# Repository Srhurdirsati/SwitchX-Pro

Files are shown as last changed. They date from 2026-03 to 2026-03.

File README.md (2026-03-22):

# SwitchX-Pro

SwitchX Pro is a 6-channel WiFi smart switch system with real-time clock automation, allowing precise control of home appliances anytime, anywhere.

## Working

1 - *Put the ESP32 in boot mode and connect it to your PCB*

2 - *Use arduino IDE to upload the CODE to the Board and* **make sure that you have entered correct SSID and it's password in the code** . *The following libraries should downloaded and transferred in the microcontroller :*

`<WiFi.h>`

`<WebServer.h>`

`<EEPROM.h>`

`<Wire.h>`

`"RTClib.h"`

`"time.h"`

**Now SwitchX-Pro will be ready to function .**

3 - *Connect the  main AC phase wire to AC slot and the 6 Appliances or switches wire ( That are needed to be operated with this PCB ) to the OUT 1-6 slots .*

4 - *Now the PCB is completely set up and would function great if everything goes as expected* :) 

5 - *Find your ESP-32 ip address by Arduino IDE serial monitor* .

6 - *Open browser on any device that is connected to same Wi-Fi and put the ip address that you found out from serial monitor from IDE* .

All set , you are now connected to SwitchX-Pro and can operate it and perform all the present functions.

### Features

> Set on and off time for each relay respectively.

> Configure onboard time.

> Toggle each relay manually.

## Images

SwitchX-Pro

1773955277817-ucqhdg

1774019621159-pjiphq

1774032290546-wd8d0q

1774023930254-0juiif

1774036756983-eu0k7x

1774040000702-8yhh15

1774117969858-60lv3o

1774117497715-0monqq

## JLCPCB

1774024000536-30i4v6

1774024062484-bg7gfw

` Project Total = 120 USD `

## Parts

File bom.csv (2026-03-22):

ID | Name | Designator | Footprint | Quantity | Manufacturer Part | Manufacturer | Supplier | Supplier Part | Price
1 | WJ500V-5.08-2P-14-00A | AC,OUT_1,OUT2,OUT3,OUT4,OUT5,OUT6 | CONN-TH_2P-P5.00_WJ500V-5.08-2P | 7 | WJ500V-5.08-2P | KANGNEX(康奈克斯电气) | LCSC | C8465 | 0.129
2 | BS-CR2032-8 | BAT1 | BAT-SMD_BS-CR2032-8 | 1 | BS-CR2032-8 | LX(连欣科技) | LCSC | C7498149 | 0.203
3 | 10uF | C1,C2 | C0805 | 2 | CL21A106KAYNNNE | SAMSUNG(三星) | LCSC | C15850 | 0.02
4 | 100nF | C9,C10 | C0805 | 2 | CC0805KRX7R9BB104 | YAGEO(国巨) | LCSC | C49678 | 0.005
5 | 1N4007 | D1,D2,D3,D4,D5,D6 | DO-41_BD2.4-L4.7-P8.70-D0.9-RD | 6 | 1N4007 | ST(先科) | LCSC | C106903 | 0.02
6 | SS34_C8678 | D7 | SMA_L4.3-W2.6-LS5.2-RD | 1 | SS34 | MDD(辰达半导体) | LCSC | C8678 | 0.03
7 | 64600001003 | FH1 | 64600001003 | 1 | 64600001003 | Littelfuse(美国力特) | LCSC | C206887 | 1.003
8 | YLED0805R | LED1,LED2,LED3,LED4,LED5,LED6 | LED0805-R-RD_RED | 6 | YLED0805R | YONGYUTAI(永裕泰) | LCSC | C19171391 | 0.008
9 | S8050D331 | Q1,Q2,Q3,Q4,Q5,Q6 | TO-92-3_L5.1-W4.1-P1.27-L | 6 | S8050D331 | ALJ(龙晶微) | LCSC | C22751469 | 0.014
10 | 1kΩ | R1,R2,R3,R4,R5,R6 | RES-TH_BD5.0-L15.5-P19.50-D0.7 | 6 | MF3WS-1KΩ±1% T | CCO(千志电子) | LCSC | C119712 | 0.063
11 | 10kΩ | R7,R15 | RES-TH_BD4.5-L11.5-P15.50-D0.7 | 2 | MF2WS-10KΩ±1%T | 华星机电 | LCSC | C714145 | 0.033
12 | 4.7kΩ | R13,R14 | R0805 | 2 | WR08X472JTL | Walsin(华新科) | LCSC | C163996 | 0.002
13 | 5.1kΩ | R16,R17 | R0402 | 2 | WR04X512JTL | Walsin(华新科) | LCSC | C384321 | 0.001
14 | SRD-05VDC-SL-C | RLY1,RLY2,RLY3,RLY4,RLY5,RLY6 | RELAY-TH_SRD-XXVDC-XL-C | 6 | SRD-05VDC-SL-C | 松乐 | LCSC | C35449 | 0.48
15 | Boot | SW1 | KEY-SMD_4P-L6.0-W6.0-P3.90-LS9.0 | 1 | TS-1095PS-A1B2-C3D2 | Yuandi(元迪) | LCSC | C2834918 | 0.056
16 | Reset | SW2 | KEY-SMD_4P-L6.0-W6.0-P3.90-LS9.0 | 1 | TS-1095PS-A1B2-C3D2 | Yuandi(元迪) | LCSC | C2834918 | 0.056
17 | ESP32-WROOM-32E(16MB) | U1 | WIFI-SMD_ESP32-WROOM-32E | 1 | ESP32-WROOM-32E-N16 | ESPRESSIF(乐鑫) | LCSC | C701343 | 4.34
18 | 220Ω | U3,U4,U5,U6,U7,U8 | RES-TH_BD2.3-L3.7-P7.70-D0.9 | 6 | MF1/8W-220Ω±1%-ST52 | VO(翔胜) | LCSC | C2848572 | 0.008
19 | AMS1117-3.3 | U9 | SOT-223-3_L6.5-W3.4-P2.30-LS7.0-BR | 1 | AMS1117-3.3 | AMS | LCSC | C6186 | 0.225
20 | HLK-PM01 | U10 | PWRM-TH_HLK-PM01 | 1 | HLK-PM01 | HI-LINK(海凌科) | LCSC | C209903 | 2.757
21 | TYPEC-700-ARP16X7 | U13 | TYPE-C-SMD_TYPEC16PL7.35MM | 1 | TYPEC-700-ARP16X7 | XUNPU(讯普) | LCSC | C7421430 | 1.37
22 | CH340C | U14 | SOP-16_L10.0-W3.9-P1.27-LS6.0-BL | 1 | CH340C | WCH(南京沁恒) | LCSC | C84681 | 0.578
23 | DS3231SN# | U2 | SOIC-16_L10.3-W7.5-P1.27-LS10.3-BL | 1 | DS3231SN#T&R | ADI(亚德诺)/MAXIM(美信) | LCSC | C9866 | 5.237

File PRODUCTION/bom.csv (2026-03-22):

Designator | Footprint | Quantity | Value | LCSC Part #
AC, OUT2, OUT3, OUT4, OUT5, OUT6, OUT_1 | CONN-TH_2P-P5.00_WJ500V-5.08-2P | 7 | WJ500V-5.08-2P-14-00A
BAT1 | BAT-SMD_BS-CR2032-8 | 1 | BS-CR2032-8
C1, C2 | C0805 | 2 | 10uF
C10, C9 | C0805 | 2 | 100nF
D1, D2, D3, D4, D5, D6 | DO-41_BD2.4-L4.7-P8.70-D0.9-RD | 6 | 1N4007
D7 | SMA_L4.3-W2.6-LS5.2-RD | 1 | C8678
FH1 | 64600001003 | 1 | 64600001003
HOLE_GGE9527 | Hole_gge9527 | 1 | Hole_gge9527
HOLE_GGE9566 | Hole_gge9566 | 1 | Hole_gge9566
HOLE_GGE9581 | Hole_gge9581 | 1 | Hole_gge9581
HOLE_GGE9596 | Hole_gge9596 | 1 | Hole_gge9596
LED1, LED2, LED3, LED4, LED5, LED6 | LED0805-R-RD_RED | 6 | YLED0805R
Q1, Q2, Q3, Q4, Q5, Q6 | TO-92-3_L5.1-W4.1-P1.27-L | 6 | S8050D331
R1, R2, R3, R4, R5, R6 | RES-TH_BD5.0-L15.5-P19.50-D0.7 | 6 | 1kΩ
R13, R14 | R0805 | 2 | 4.7kΩ
R15, R7 | RES-TH_BD4.5-L11.5-P15.50-D0.7 | 2 | 10kΩ
R16, R17 | R0402 | 2 | 5.1kΩ
RLY1, RLY2, RLY3, RLY4, RLY5, RLY6 | RELAY-TH_SRD-XXVDC-XL-C | 6 | SRD-05VDC-SL-C
SW1 | KEY-SMD_4P-L6.0-W6.0-P3.90-LS9.0 | 1 | Boot
SW2 | KEY-SMD_4P-L6.0-W6.0-P3.90-LS9.0 | 1 | Reset
U1 | WIFI-SMD_ESP32-WROOM-32E | 1 | ESP32
U10 | PWRM-TH_HLK-PM01 | 1 | HLK-PM01
U13 | TYPE-C-SMD_TYPEC16PL7.35MM | 1 | TYPEC-700-ARP16X7
U14 | SOP-16_L10.0-W3.9-P1.27-LS6.0-BL | 1 | CH340C
U2 | SOIC-16_L10.3-W7.5-P1.27-LS10.3-BL | 1 | DS3231SN#
U3, U4, U5, U6, U7, U8 | RES-TH_BD2.3-L3.7-P7.70-D0.9 | 6 | 220Ω
U9 | SOT-223-3_L6.5-W3.4-P2.30-LS7.0-BR | 1 | AMS1117-3.3

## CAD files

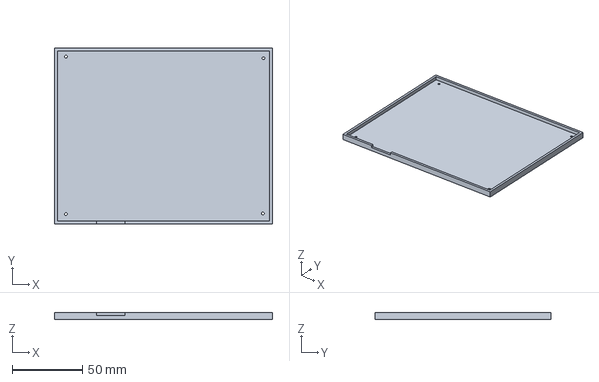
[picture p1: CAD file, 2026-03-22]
CAD/BASE.FCStd
155.0 x 125.0 x 5.00 mm

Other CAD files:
CAD/Assembly.FCStd

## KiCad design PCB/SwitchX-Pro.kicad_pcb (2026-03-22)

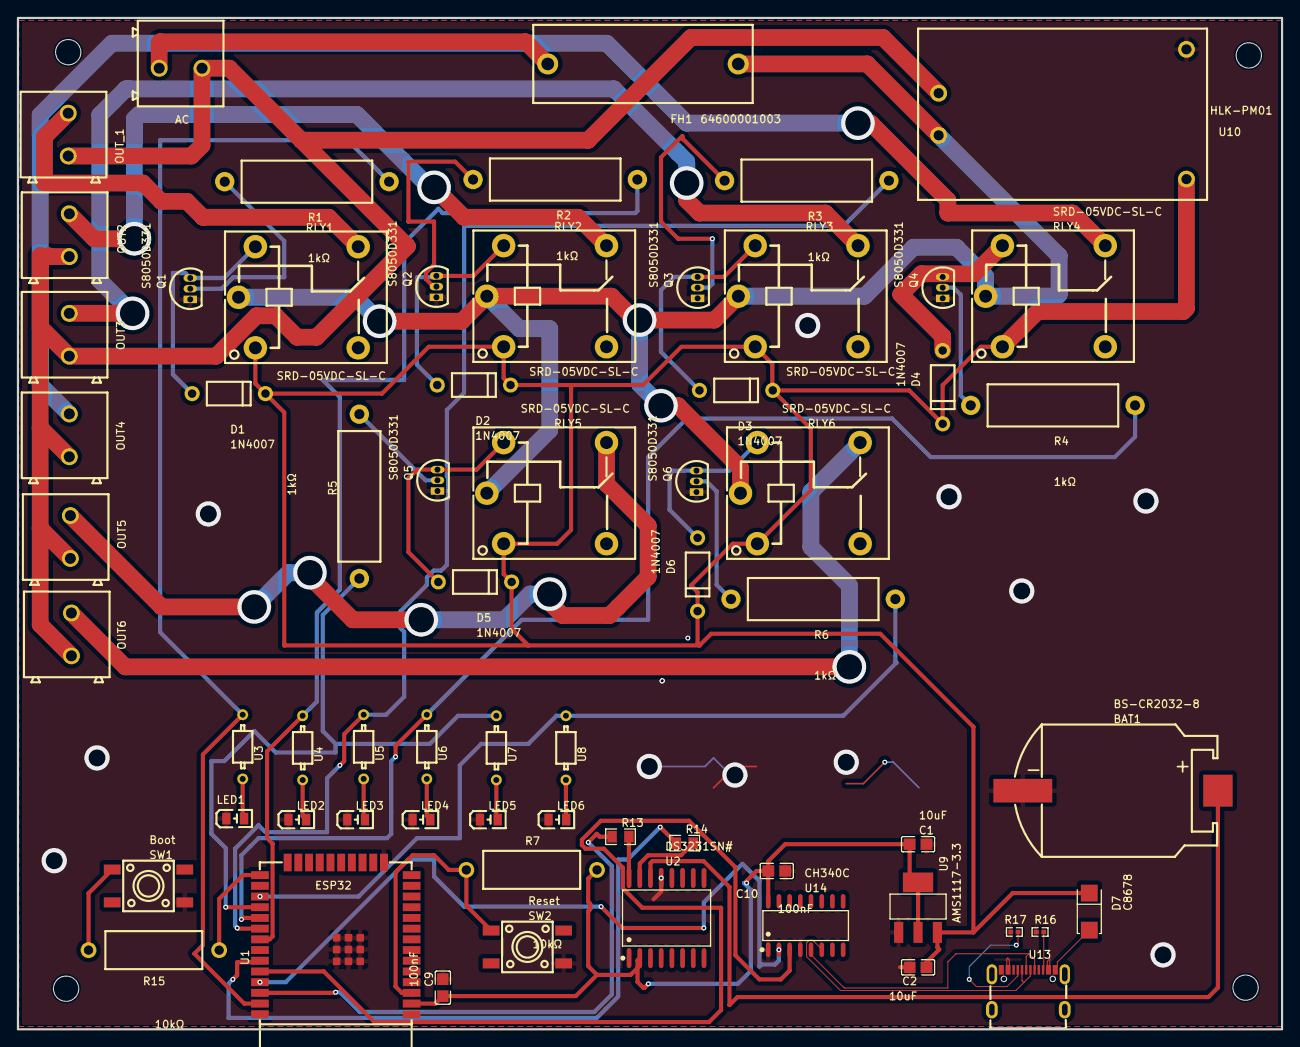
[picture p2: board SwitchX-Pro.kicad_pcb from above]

Board: 2 copper layers, 150.0 x 120.0 mm, 68 parts (0 on the bottom side), 51 nets.

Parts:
AC: WJ500V-5.08-2P-14-00A; CONN-TH_2P-P5.00_WJ500V-5.08-2P
BAT1: BS-CR2032-8; BAT-SMD_BS-CR2032-8
C1, C2: 10uF; C0805
C9, C10: 100nF; C0805
D1, D2, D3, D4, D5, D6: 1N4007; DO-41_BD2.4-L4.7-P8.70-D0.9-RD
D7: C8678; SMA_L4.3-W2.6-LS5.2-RD
FH1: 64600001003
Hole_gge9527: Hole_gge9527
Hole_gge9566: Hole_gge9566
Hole_gge9581: Hole_gge9581
Hole_gge9596: Hole_gge9596
LED1, LED2, LED3, LED4, LED5, LED6: YLED0805R; LED0805-R-RD_RED
OUT2, OUT3, OUT4, OUT5, OUT6: WJ500V-5.08-2P-14-00A; CONN-TH_2P-P5.00_WJ500V-5.08-2P
OUT_1: WJ500V-5.08-2P-14-00A; CONN-TH_2P-P5.00_WJ500V-5.08-2P
Q1, Q2, Q3, Q4, Q5, Q6: S8050D331; TO-92-3_L5.1-W4.1-P1.27-L
R1, R2, R3, R4, R5, R6: 1kΩ; RES-TH_BD5.0-L15.5-P19.50-D0.7
R7, R15: 10kΩ; RES-TH_BD4.5-L11.5-P15.50-D0.7
R13, R14: 4.7kΩ; R0805
R16, R17: 5.1kΩ; R0402
RLY1, RLY2, RLY3, RLY4, RLY5, RLY6: SRD-05VDC-SL-C; RELAY-TH_SRD-XXVDC-XL-C
SW1: Boot; KEY-SMD_4P-L6.0-W6.0-P3.90-LS9.0
SW2: Reset; KEY-SMD_4P-L6.0-W6.0-P3.90-LS9.0
U1: ESP32; WIFI-SMD_ESP32-WROOM-32E
U2: DS3231SN#; SOIC-16_L10.3-W7.5-P1.27-LS10.3-BL
U3, U4, U5, U6, U7, U8: 220Ω; RES-TH_BD2.3-L3.7-P7.70-D0.9
U9: AMS1117-3.3; SOT-223-3_L6.5-W3.4-P2.30-LS7.0-BR
U10: HLK-PM01; PWRM-TH_HLK-PM01
U13: TYPEC-700-ARP16X7; TYPE-C-SMD_TYPEC16PL7.35MM
U14: CH340C; SOP-16_L10.0-W3.9-P1.27-LS6.0-BL

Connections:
3.3V: C1.1, C9.1, C10.2, R7.1, U1.2, U2.2, U9.2, U9.4, U14.16
5V: C2.1, D1.1, D2.1, D3.1, D4.1, D5.1, D6.1, D7.1, RLY1.1, RLY2.1, RLY3.1, RLY4.1, RLY5.1, RLY6.1, U9.3, U10.4
AC_MAIN: AC.1, FH1.1
BOOT: R15.1, U1.25
D+: U13.A6, U13.B6, U14.5
D-: U13.A7, U13.B7, U14.6
EN: R7.2, SW2.1, U1.3
GND: BAT1.1, C1.2, C2.2, C9.2, C10.1, LED1.2, LED2.2, LED3.2, LED4.2, LED5.2, LED6.2, Q1.1, Q2.1, Q3.1, Q4.1, Q5.1, Q6.1, R16.1, R17.1, SW1.4, SW2.4, U1.1, U1.15, U1.38, U1.39, U2.13, U9.1, U10.3, U13.A4, U13.A9, U13.B4, U13.B9, U14.1, U14.4
LED1_1: LED1.1, U3.2
LED2_1: LED2.1, U4.2
LED3_1: LED3.1, U5.2
LED4_1: LED4.1, U6.2
LED5_1: LED5.1, U7.2
LED6_1: LED6.1, U8.2
LIVE: FH1.2, RLY1.5, RLY2.5, RLY3.5, RLY4.5, RLY5.5, RLY6.5, U10.2
LIVE_1: OUT_1.2, RLY1.3
LIVE_2: OUT2.2, RLY2.3
LIVE_3: OUT3.2, RLY3.3
LIVE_4: OUT4.2, RLY4.3
LIVE_5: OUT5.2, RLY5.3
LIVE_6: OUT6.2, RLY6.3
NEUTRAL: AC.2, OUT2.1, OUT3.1, OUT4.1, OUT5.1, OUT6.1, OUT_1.1, U10.1
Q1_2: Q1.2, R1.2
Q2_2: Q2.2, R2.2
Q3_2: Q3.2, R3.2
Q4_2: Q4.2, R4.2
Q5_2: Q5.2, R5.2
Q6_2: Q6.2, R6.2
RELAY_1: R1.1, U1.37, U3.1
RELAY_2: R2.1, U1.31, U4.1
RELAY_3: R3.1, U1.30, U5.1
RELAY_4: R4.1, U1.29, U6.1
RELAY_5: R5.1, U1.28, U7.1
RELAY_6: R6.1, U1.27, U8.1
RLY1_4: D1.2, Q1.3, RLY1.4
RLY2_4: D2.2, Q2.3, RLY2.4
RLY3_4: D3.2, Q3.3, RLY3.4
RLY4_4: D4.2, Q4.3, RLY4.4
RLY5_4: D5.2, Q5.3, RLY5.4
RLY6_4: D6.2, Q6.3, RLY6.4
RXD: U1.34, U14.3
SCL: R13.1, U1.36
SDA: R14.1, U1.33
SW1_1: R15.2, SW1.1
TXD: U1.35, U14.2
U2_15: R14.2, U2.15
U2_16: R13.2, U2.16
U13_A5: R17.2, U13.A5
U13_B5: R16.2, U13.B5
U13_B12: D7.2, U13.A12, U13.B12
VBAT: BAT1.2, U2.14

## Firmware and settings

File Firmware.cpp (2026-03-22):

#include <WiFi.h>
#include <WebServer.h>
#include <EEPROM.h>
#include <Wire.h>
#include "RTClib.h"
#include "time.h"

RTC_DS3231 rtc;
WebServer server(80);

// WIFI
const char* ssid = "YOUR_WIFI";
const char* password = "YOUR_PASS";

// NTP
const char* ntpServer = "pool.ntp.org";
const long gmtOffset_sec = 19800;

// RELAYS
int relays[6] = {23,19,18,5,17,16};
bool relayState[6];

#define EEPROM_SIZE 10

// ---------- SAVE / LOAD ----------
void saveState(){
  for(int i=0;i<6;i++){
    EEPROM.write(i, relayState[i]);
  }
  EEPROM.commit();
}

void loadState(){
  for(int i=0;i<6;i++){
    relayState[i] = EEPROM.read(i);
    pinMode(relays[i], OUTPUT);
    digitalWrite(relays[i], relayState[i]);
  }
}

// ---------- TIME SYNC ----------
void syncRTC(){
  struct tm timeinfo;
  if(getLocalTime(&timeinfo)){
    rtc.adjust(DateTime(
      timeinfo.tm_year+1900,
      timeinfo.tm_mon+1,
      timeinfo.tm_mday,
      timeinfo.tm_hour,
      timeinfo.tm_min,
      timeinfo.tm_sec
    ));
  }
}

// ---------- WEB UI ----------
String page(){

  DateTime now = rtc.now();

  struct tm timeinfo;
  getLocalTime(&timeinfo);

  String deviceTime = String(timeinfo.tm_hour)+":"+String(timeinfo.tm_min)+":"+String(timeinfo.tm_sec);
  String rtcTime = String(now.hour())+":"+String(now.minute())+":"+String(now.second());

  String html = R"rawliteral(
  <html>
  <head>
  <meta name="viewport" content="width=device-width, initial-scale=1">
  <style>
  body {
    margin:0;
    font-family:Segoe UI;
    background: linear-gradient(135deg,#0f2a2f,#2c4f56);
    color:#e8f0f2;
  }
  h1{text-align:center;margin-top:20px;}
  .clock{text-align:center;margin-bottom:15px;}
  .grid{
    display:grid;
    grid-template-columns:repeat(auto-fit,minmax(220px,1fr));
    gap:20px;padding:20px;
  }
  .card{
    background:rgba(255,255,255,0.08);
    border-radius:15px;padding:20px;position:relative;
  }
  .info{
    position:absolute;top:10px;right:15px;cursor:pointer;
  }
  .switch{
    position:relative;display:inline-block;width:50px;height:26px;margin-top:10px;
  }
  .switch input{display:none;}
  .slider{
    position:absolute;top:0;left:0;right:0;bottom:0;
    background:#666;border-radius:34px;
  }
  .slider:before{
    content:"";position:absolute;height:20px;width:20px;
    left:3px;bottom:3px;background:white;border-radius:50%;
    transition:.3s;
  }
  input:checked + .slider{background:#4cd964;}
  input:checked + .slider:before{transform:translateX(24px);}
  button{
    padding:6px 10px;margin-top:10px;border:none;border-radius:5px;
    background:#4cd964;cursor:pointer;
  }
  .footer{text-align:center;margin-top:20px;opacity:0.6;}
  </style>
  </head>

  <body>

  <h1>SwitchX Pro</h1>

  <div class="clock">
    RTC Time: )rawliteral";

  html += rtcTime;

  html += R"rawliteral(<br>
    Device Time: )rawliteral";

  html += deviceTime;

  html += R"rawliteral(
  </div>

  <div style="text-align:center;">
    <a href="/sync"><button>Sync Time</button></a>
  </div>

  <div class="grid">
  )rawliteral";

  for(int i=0;i<6;i++){
    String checked = relayState[i] ? "checked" : "";

    html += "<div class='card'>";
    html += "<h3>Relay "+String(i+1)+"</h3>";

    html += "<label class='switch'>";
    html += "<input type='checkbox' "+checked+" onclick='location.href=\"/toggle?r="+String(i)+"\"'>";
    html += "<span class='slider'></span></label>";

    html += "</div>";
  }

  html += R"rawliteral(
  </div>

  <div class="footer">
    Made by Sarthak Tripathi
  </div>

  </body>
  </html>
  )rawliteral";

  return html;
}

// ---------- HANDLERS ----------
void handleRoot(){ server.send(200,"text/html",page()); }

void handleToggle(){
  int r = server.arg("r").toInt();
  relayState[r] = !relayState[r];
  digitalWrite(relays[r], relayState[r]);
  saveState();
  server.sendHeader("Location","/");
  server.send(303);
}

void handleSync(){
  syncRTC();
  server.sendHeader("Location","/");
  server.send(303);
}

// ---------- SETUP ----------
void setup(){

  Serial.begin(115200);

  EEPROM.begin(EEPROM_SIZE);
  loadState();

  Wire.begin();
  rtc.begin();

  WiFi.begin(ssid,password);
  while(WiFi.status()!=WL_CONNECTED){
    delay(500);
  }

  Serial.println(WiFi.localIP());

  configTime(gmtOffset_sec,0,ntpServer);

  server.on("/",handleRoot);
  server.on("/toggle",handleToggle);
  server.on("/sync",handleSync);

  server.begin();
}

// ---------- LOOP ----------
void loop(){
  server.handleClient();
}
